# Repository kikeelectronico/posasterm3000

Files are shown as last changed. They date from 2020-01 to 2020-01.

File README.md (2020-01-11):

# Posasterm 3000

Posaterm 3000 es un simple posavasos que indica la temperatura de la bebida encendiendo uno de los LEDs de su anillo.

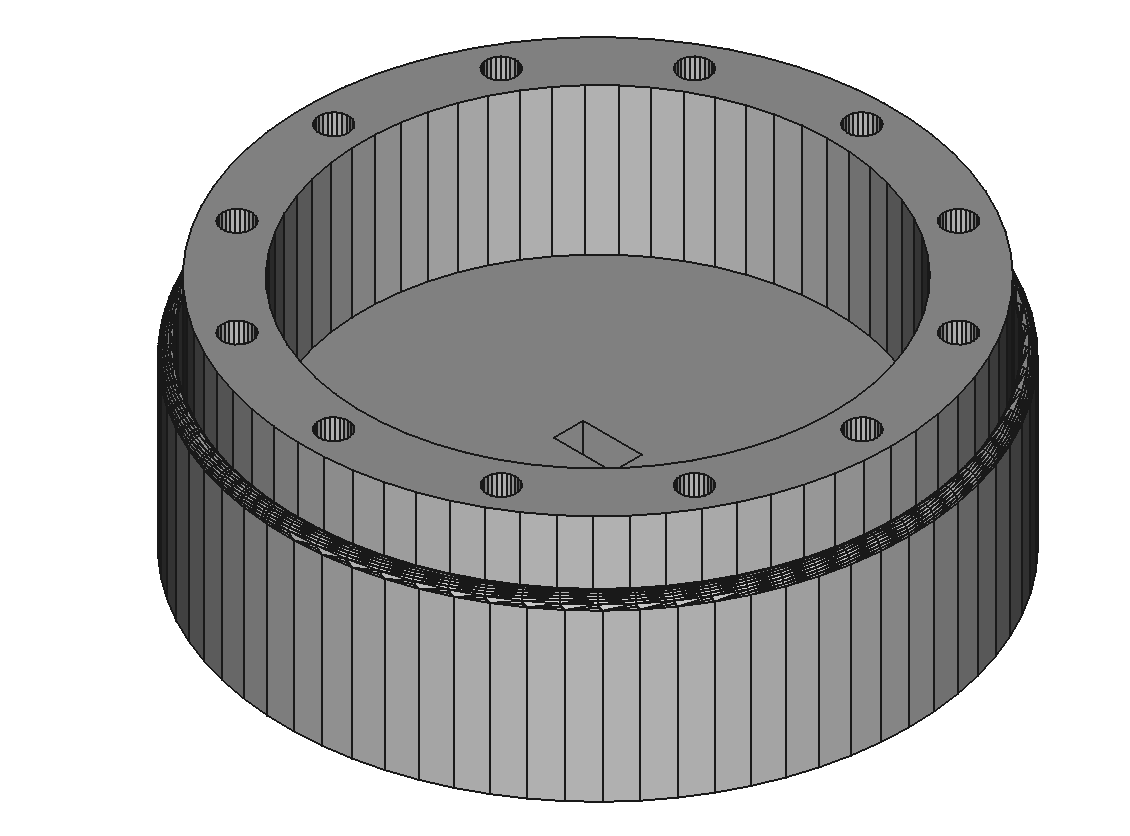
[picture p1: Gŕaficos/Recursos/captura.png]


# Materiales

- Arduino Nano, sin headers.
- 12 LEDs de 5 mm.
al- 12 resistencias para los LEDs. Aprende a calcularlas en este tutorial [https://www.rinconingenieril.es/usar-los-led/](https://www.rinconingenieril.es/usar-los-led/)
- Cable para conexiones. Por ejemplo de 0.25 mm².
- NTC.
- Resistencia del mismo valor que la R0 de la NTC.
- Cable USB para Arduino.
- Fuente de alimentación de 5v.
- 2 x Tornillo M3 10mm.
- 2 x Tuerca M3.

# Construcción

1. Imprimir la parte superior y la parte inferior con una impresora 3D.
2. Montar los LEDs con sus respectivas resistencias en la parte superior.
3. Montar la NTC y su circuito de acondicionamiento en la parte superior.
4. Conectar los LEDs y la NTC al Arduino Nano.
5. Cargar el firmware Posaterm300.

Video de construcción: Dispobible en breve.

# Avisos

- Si en el circuito de acondicionamiento de la NTC recibe más o menos de 5v se debe modificar la variable Vcc del firmware. Si es mayor a 5v, ten cuidado de no quemar el ADC de Arduino.
- La NTC sufre autocalentamiento, así que, cuando cada vez que se enciende tardará varios minutos en indicar la temperatura correcta. Puedes aprender a usar una NTC con este tutorial: [https://www.rinconingenieril.es/como-usar-un-termistor-ntc/](https://www.rinconingenieril.es/como-usar-un-termistor-ntc/)
- Debido al autocalentamiento la temperatura indicada puede ser algunos grados mayor a la real. Este error no es significativo en la mayoría de ocasiones para Posaterm 3000.

# Licencia
Creative Commons Atribución-CompartirIgual 4.0 Internacional.

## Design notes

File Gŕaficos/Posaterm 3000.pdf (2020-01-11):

# Posaterm 3000

### ¿Qué es Posaterm 3000?

### ¿Cómo funciona?

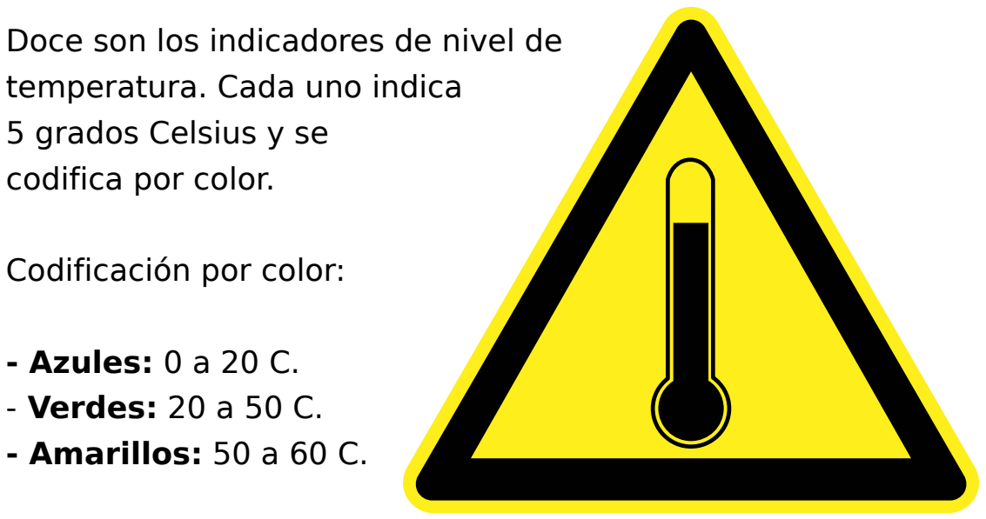
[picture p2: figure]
Doce son los indicadores de nivel de temperatura. Cada uno indica 5 grados Celsius y se codifica por color.; Codificación por color:; - Azules: 0 a 20 C. - Verdes: 20 a 50 C. - Amarillos: 50 a 60 C.

Esta obra está bajo una Licencia
Creative Commons Atribución-CompartirIgual 4.0 Internacional.

Enhorabuena por la adquisición de su Posaterm 3000. Desde Neoengineering creemos en el futuro seguro, por esto estamos realmente convencidos de que no se arrepentirá de su adquisición intertemporal.

Un posavasos capaz de detectar la temperatura de su bebida.
Es bien sabido por todos que antes de salvar a la humanidad de los androides infiltrados hay que tomarse un café a la temperatura correcta.

Coge el alimentador del replicante, conéctalo a un enchufe del presente y a su nuevo Posaterm 3000. Ha de esperar un minuto a que se produzca el autocalentamiento del dispositivo.

Para replicar este proyecto visita http://bit.ly/posaterm3000

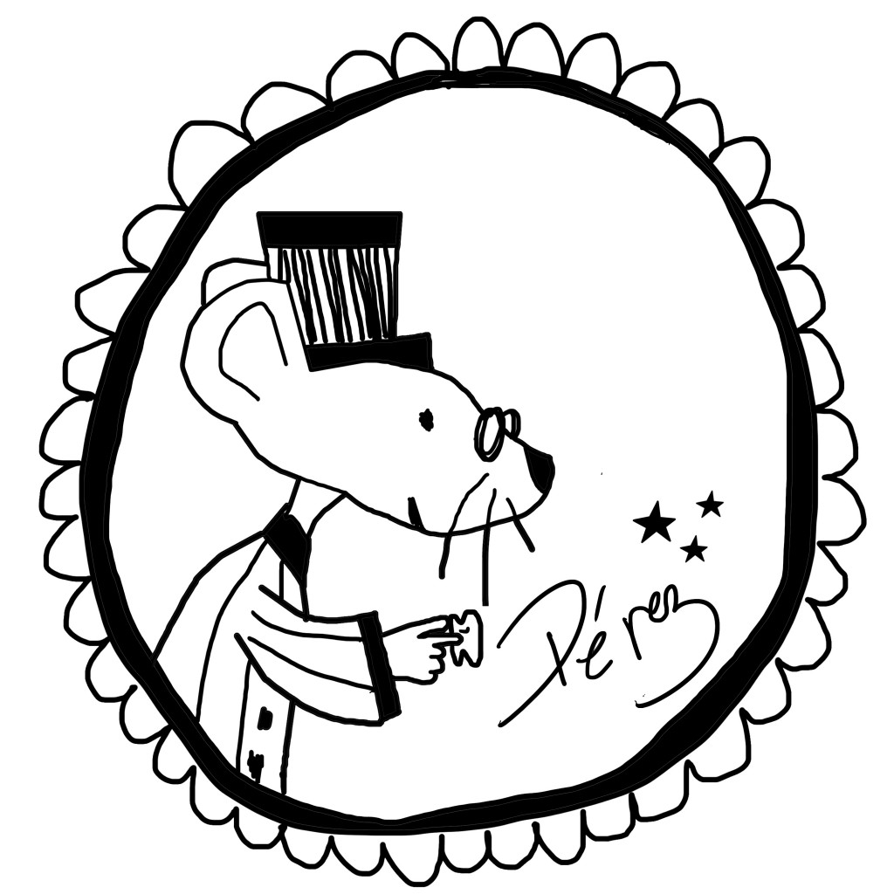
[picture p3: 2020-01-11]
Gŕaficos/Recursos/Perez.jpg

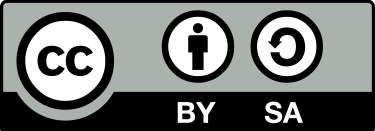
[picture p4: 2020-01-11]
Gŕaficos/Recursos/by-sa.svg.png

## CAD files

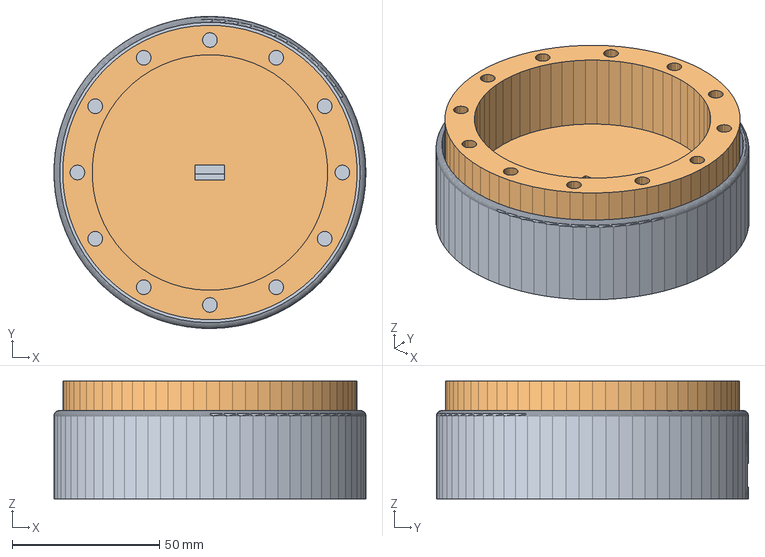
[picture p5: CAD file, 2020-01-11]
3D/Assembly STL.FCStd
106.0 x 106.0 x 40.0 mm
Inferior_1_1003
Superior002

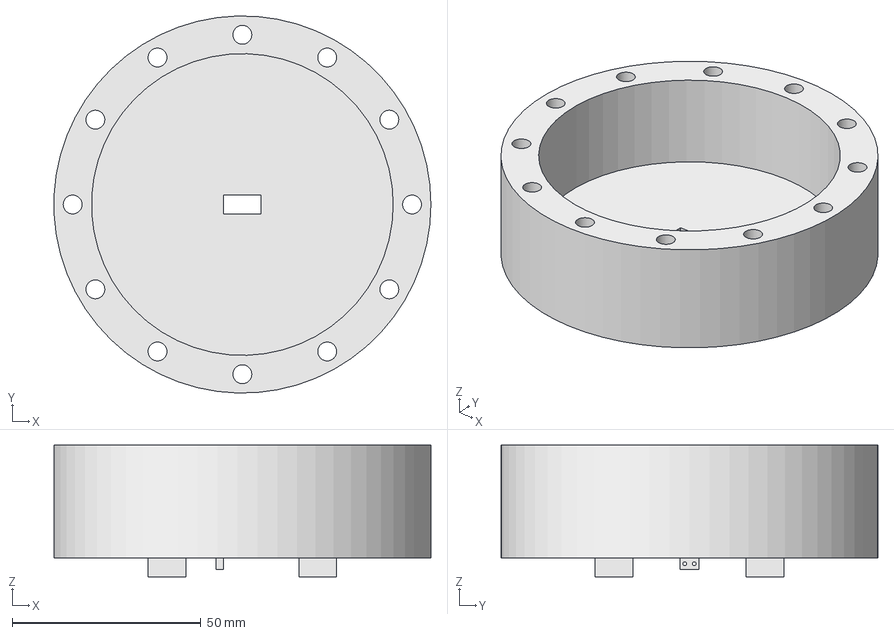
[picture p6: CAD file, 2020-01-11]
3D/Superior.FCStd
99.9 x 100.0 x 35.0 mm

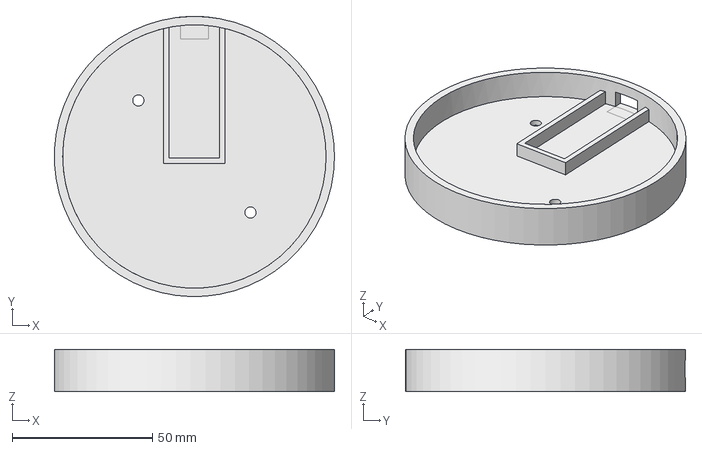
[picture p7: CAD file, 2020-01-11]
3D/Inferior_1.FCStd
99.9 x 100.0 x 15.0 mm

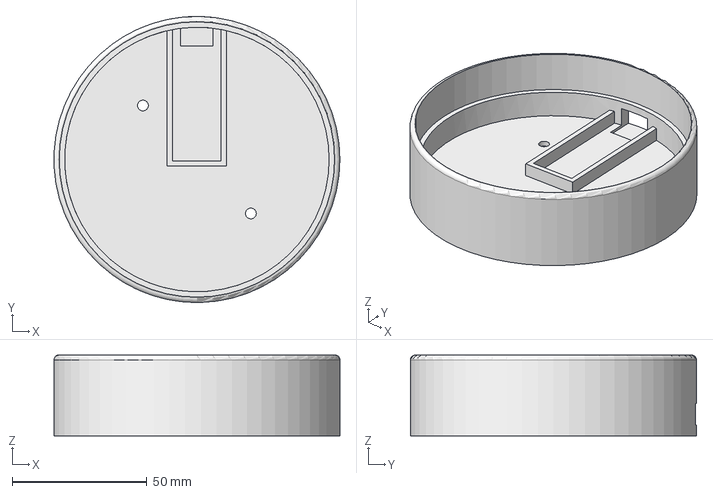
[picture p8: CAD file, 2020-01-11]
3D/Inferior_2.FCStd
105.9 x 106.0 x 30.0 mm

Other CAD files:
3D/Inferior_1.stl
3D/Inferior_2.stl
3D/Superior.stl

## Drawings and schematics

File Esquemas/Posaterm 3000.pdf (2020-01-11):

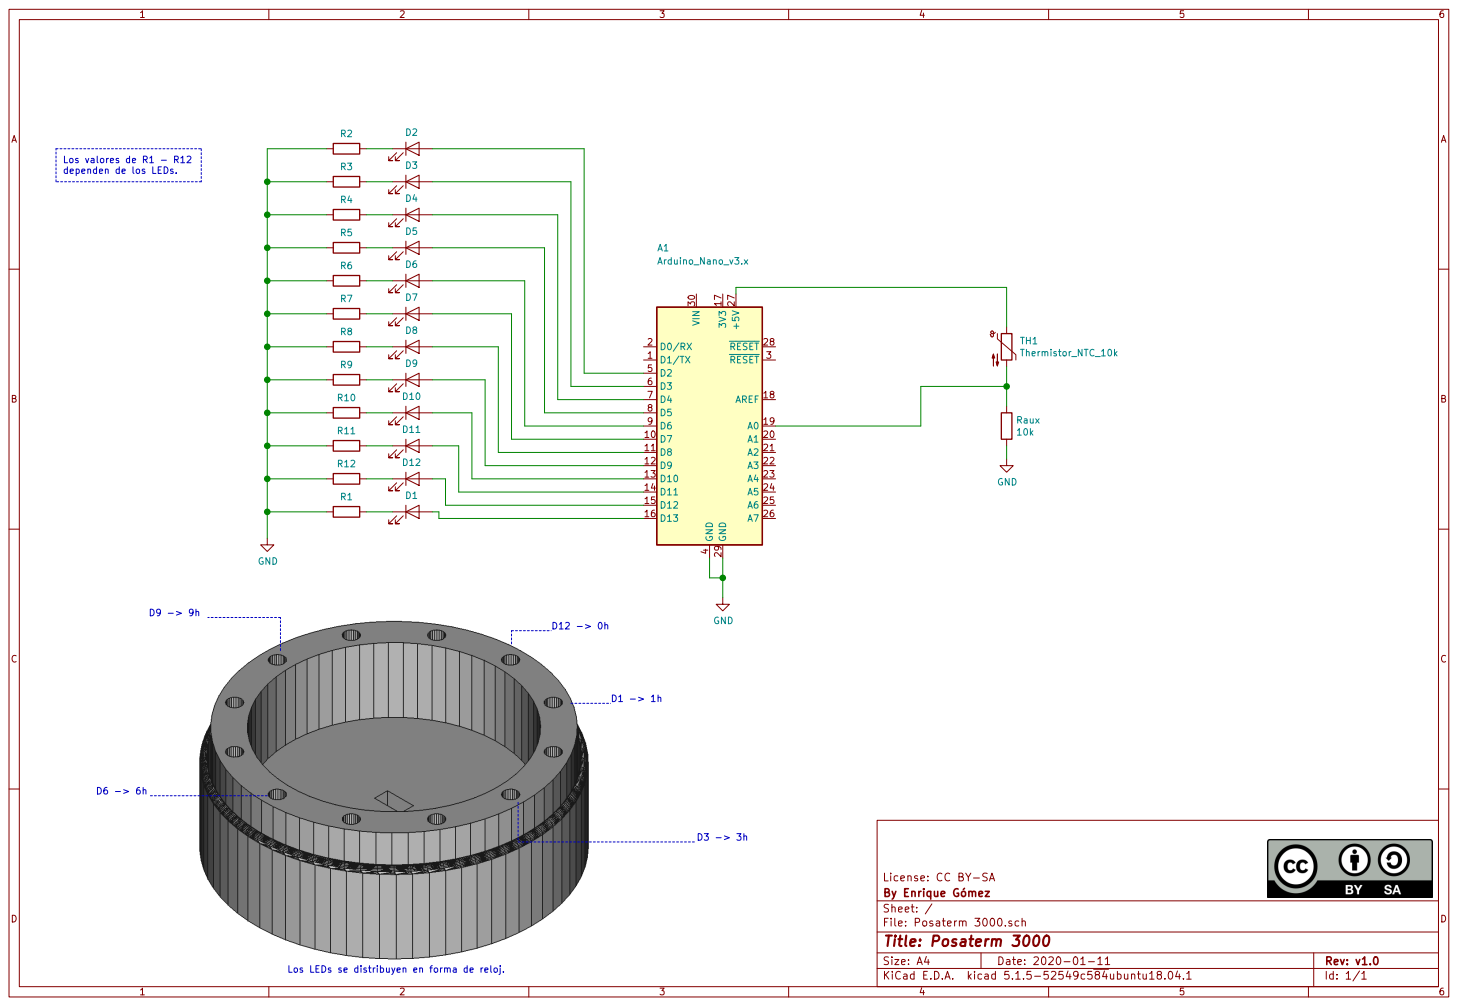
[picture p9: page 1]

File: Posaterm 3000.sch Sheet: / By Enrique Gómez License: CC BY-SA

Los LEDs se distribuyen en forma de reloj.

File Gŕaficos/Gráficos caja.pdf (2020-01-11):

# Posaterm 3000

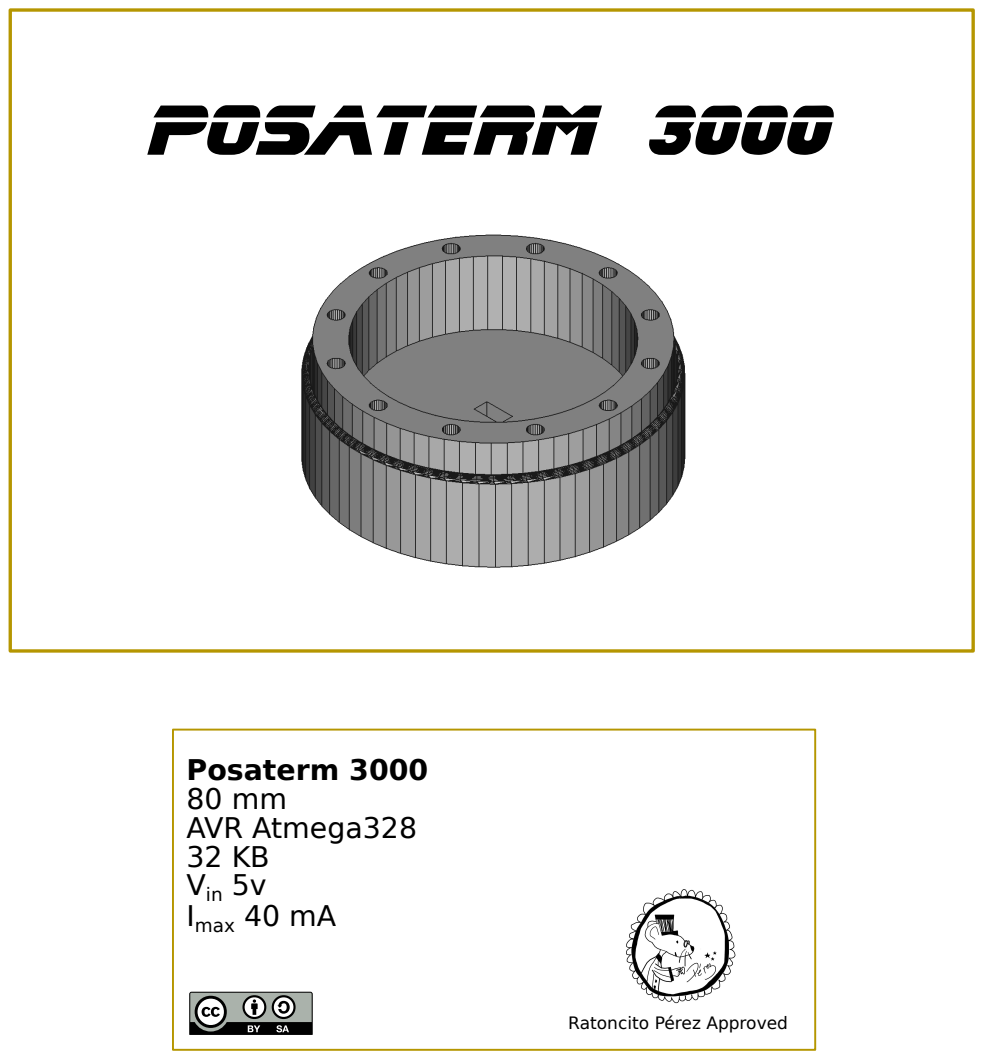
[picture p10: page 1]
Posaterm 3000 80 mm AVR Atmega328 32 KB Vin 5v Imax 40 mA

Ratoncito Pérez Approved

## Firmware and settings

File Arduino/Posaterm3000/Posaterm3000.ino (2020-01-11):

#include <math.h>

//Valores constantes del circuito
float rAux = 10000.0;
float vcc = 5.0;
int mapeo[12] = {12,13,2,3,4,5,6,7,8,9,10,11};

//Valores constantes de la NTC
float beta = 3977.0;
float temp0 = 298.0;
float r0 = 10000.0;

//Variables usadas en el cálculo
float vm = 0.0;
float rntc = 0.0;
float temperaturaK = 0.0;
int led = 0;


void setup() {
  Serial.begin(115200);
  //LEDs como salidas y apagadoss
  for(int i = 13; i >1; i--){
    pinMode(i, OUTPUT);
    digitalWrite(i, LOW);
  }
}

void loop() {

  //Bloque de cálculo
  vm=(vcc / 1024)*( analogRead(0) );                      //Calcular tensión en la entrada
  rntc = rAux / ((vcc/(vcc-vm))-1);                       //Calcular la resistencia de la NTC
  temperaturaK = beta/(log(rntc/r0)+(beta/temp0));        //Calcular la temperatura en Kelvin
  //Restar 273 para pasar a grados celsus
  Serial.print(temperaturaK - 273);
  //Calcular LED a encender
  led = (temperaturaK-273)/5;  
  Serial.print(" - ");  
  Serial.println(led);
  
  //Apagar todos los LEDs
  for(int i = 0; i < 13; i++)
    digitalWrite(mapeo[i], LOW);
  digitalWrite(mapeo[led], HIGH);
  
  delay(1000); 
}

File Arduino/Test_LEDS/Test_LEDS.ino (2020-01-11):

void setup() {
  for(int i = 13; i >1; i--){
    pinMode(i, OUTPUT);
    digitalWrite(i, LOW);
  }

}

void loop() {
  for(int i = 2; i <14; i++){
    digitalWrite(i,!digitalRead(i));
    delay(500);    
    digitalWrite(i,!digitalRead(i));
  }
  for(int i = 13; i >1; i--){
    digitalWrite(i,!digitalRead(i));
    delay(500);    
    digitalWrite(i,!digitalRead(i));
  }
}

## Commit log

2020-01-11 posaterm 3000
    [Assembly STL.FCStd, Inferior_1.FCStd, Inferior_1.stl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]
2020-01-11 Nuts & bolts
